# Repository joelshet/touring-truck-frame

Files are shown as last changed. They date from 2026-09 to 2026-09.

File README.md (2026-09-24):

# Touring truck frame: corner bracket

A parametric corner bracket for a touring truck frame. The frame uses 80/20 15-series 3030 extrusion, and each bracket is three plywood plates cut on a laser. The post runs through the corner and the two rails butt into it. The three plates overlap each other in a cycle. Along each edge, the overlapping plate has a finger at every bolt and the other plate fills the gaps. Button-head bolts go through those fingers into captive hex nuts in the edge of the next plate.

## Cut files

These are ready to cut, in `out/`:

- `bottom.dxf`, `side.dxf`, `front.dxf`: one of each per corner, in inches, kerf-compensated
- `bottom.svg`, `side.svg`, `front.svg`: the same parts as SVG
- `parts.svg`: all three side by side
- `preview.svg`: the parts with the extrusion footprints shaded, for checking only. Don't cut this one.

The cut files are built for 7/16" sheet (measured) and a 0.2 mm kerf. If your sheet measures differently, change `T` and regenerate.

## Regenerate

Needs [uv](https://docs.astral.sh/uv/). The first run downloads build123d.

```bash
uv run bracket.py
```

The script writes everything in `out/` and prints the part sizes. It stops with an error if any cut collides with another or breaks through an edge.

## Parameters to check before cutting

All of them are at the top of `bracket.py`, in inches.

- `T`: measured sheet thickness. The part sizes, bolt positions and nut slots all follow it.
- `KERF`: laser kerf. Outlines move out and holes move in by half of it. Set it to 0 if the laser software compensates.
- `CLEAR`: extra room in joint holes, nut pockets, counterbores and finger notches for fit.
- `FINGER_W`: width of the finger around each bolt. 0 turns the fingers off and goes back to a plain overlap.
- `HEAD_RECESS`: counterbore depth for the joint bolt heads. 0 leaves the heads on the face, and `HEAD_H` sinks them flush. The laser doesn't cut counterbores. Flush counterbores leave less than 1/16" of wood at the outside edge on 1/2" ply, and the script warns about this.

## Hardware per corner

- 9 x #10-24 x 2" button head bolts, with 9 hex nuts (3/8" across flats), to join the plates
- 5/16-18 bolts with 15-series T-nuts into the extrusion slots. The four holes in the bottom plate's corner go into the post's tapped end bores.

## Other outputs

- `corner.svg`, `corner_outside.svg` and `corner_rails.svg`: line drawings of the assembled corner from inside, from outside, and with the extrusions
- `corner.step` and `corner.stl`: 3D model in mm

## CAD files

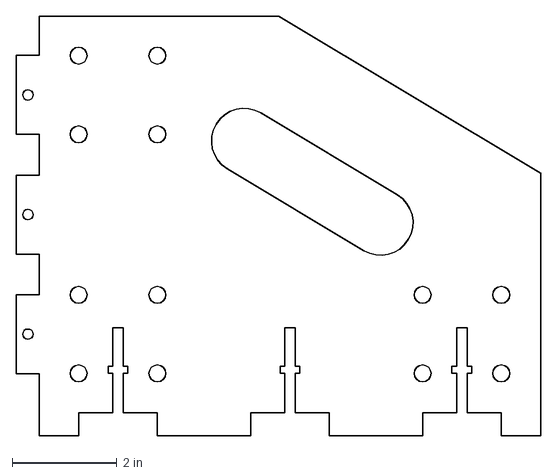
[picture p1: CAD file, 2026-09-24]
out/side.dxf
10.0 x 8.01 in

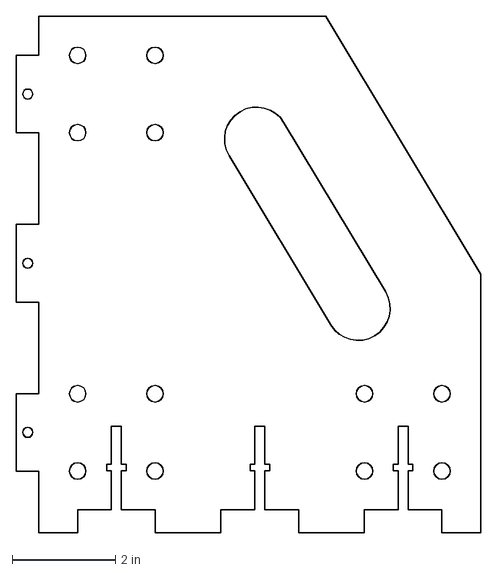
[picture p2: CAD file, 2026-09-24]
out/bottom.dxf
9.01 x 10.0 in

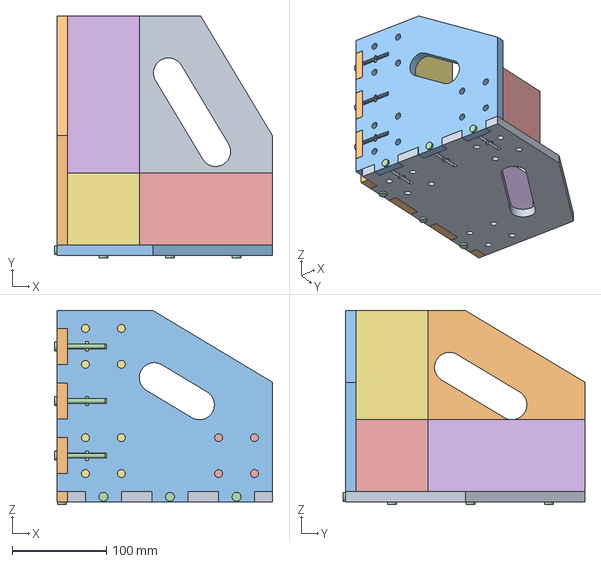
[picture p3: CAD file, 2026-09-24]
out/corner.step
231.3 x 256.7 x 205.9 mm

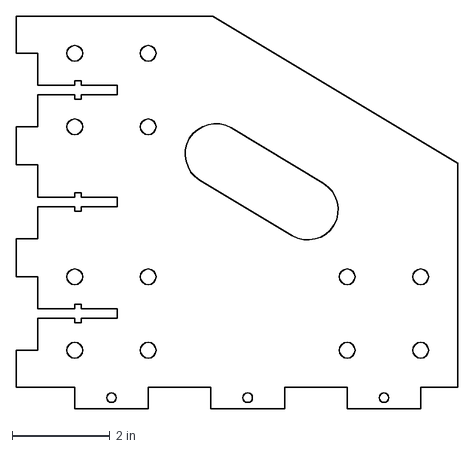
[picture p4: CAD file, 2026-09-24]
out/front.dxf
9.01 x 8.01 in

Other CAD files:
out/corner.stl

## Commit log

2026-09-24 Parametric corner bracket for 3030 extrusion frame
    Three laser-cut plywood plates per corner, cycled overlaps, button head
    bolts into captive hex nuts, rail and post holes for 80/20 3030, and
    kerf-compensated DXF/SVG cut files in out/.
    [bottom.dxf, corner.step, corner.stl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]
2026-09-24 Add finger joints and set sheet to measured 7/16"
    Each bolt now passes through a 1.5" finger on the overlapping plate, and
    the other plate fills the gaps. The script warns when hex nut corners
    stand proud of a thin sheet. Adds an outside view of the corner.
    [bottom.dxf, corner.step, corner.stl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]
2026-09-24 Use #10-24 joint hardware for the 7/16" test cut
    Button heads 0.375 x 0.105, hex nuts 3/8 across flats x 1/8. The nut
    now fits within the sheet thickness.
    [bottom.dxf, corner.step, corner.stl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]
2026-09-24 Size handles to clear the extrusion footprints
    Each handle runs parallel to its angled edge and is as long as it can be
    while staying clear of the 3" extrusions and keeping HANDLE_WEB of wood
    from the plate edges. Adds preview.svg with the footprints shaded.
    [bottom.dxf, corner.step, corner.stl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]
2026-10-25 Add Handibot setups and a 3.25 in laser variant
    Handibot: one flat setup per plate plus two edge-up setups for the stacked
    plates, written to out/handibot/ with steps.txt.
    Variants: `uv run bracket.py small` writes out/small/, a laser-only bracket
    with 3.25 in plates in 1/4 in ply for single 2020 extrusion, M3 joint
    hardware and M5 rail bolts.
    Handles: on a plate too small for the full handle, the handle and the wood
    around it shrink by one factor until it fits. Plates that fit the full
    handle are unchanged.
2026-10-25 Write model.json and sheet.json for the site's drawing sheet
    model.json is each part's edges and mesh in mm, with the extrusion marked as
    context. sheet.json is the title block and the files to cut. The DXF and STEP
    files differ only in their timestamps.
